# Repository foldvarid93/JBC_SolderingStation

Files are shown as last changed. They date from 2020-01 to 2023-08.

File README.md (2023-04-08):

# Welcome! 
## Actually you are watching my JBC soldering station project. 
## Version 1 will be improved at some points however it works fine too.
#### Planned Improvements:
##### Software and application 
- USB-C connector will be used to update the software in DFU mode. USB2.0 HS will be used
- FREERTOS will be used for task scheduling 
- The software application will be more flexible for migrate to other MCUs
- StemWin GUI will remain for STM32F4 or higher, 16x2 LCD driver will be used for slower MCUs 
- ...

##### Hardware and PCB
- PCB will remain the same size 
- AC transformer with triac will remain to avoid SMPS's high frequency noise
- Opamp will be revised if it is possible it will be changed to a better one
- Zero crossing detection may be changed to a more simple one
- Ambient temperature sensor and I2C connection will be removed
- ...

## ;)

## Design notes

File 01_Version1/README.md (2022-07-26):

# JBC Soldering Station 

This project was created to help people who would use a C245 and C470 JBC handle and cartridge without the expensive controller. 
There is some project on the internet what provides a solution. My first steps was also to find a complete method or solution.
Here is some already existing projects.
- [Marco Reps](https://drive.google.com/file/d/0B6S_PcWWM1YlY1lORkhDcTAzdEU/view)
- [Great Scot](https://www.instructables.com/id/DIY-Arduino-Soldering-Station)
- [Sparkybg](http://dangerousprototypes.com/forum/index.php?topic=7218.0#p61175)

## Criterias
There are some basic problems with those solution. I don't have an Arduino and I don't want to use that. 

**I wanted to...** 
- Use PID control to provide stable temperature on the end of the tip :heavy_check_mark:
- Use LCD display that I have bought long-long time ago :heavy_check_mark:
- Build the HW with components that I already had :heavy_check_mark:
- Implement sleep function :heavy_check_mark:
- Make 3D printed housing with individual design :heavy_check_mark:
- Have individual PCB design :heavy_check_mark:
- Use encoder as user input :heavy_check_mark:
- Use SPI thermocouple interface IC :heavy_multiplication_x:

So, to sum up the above mentioned points there is no universal solution. Okay, Unisolder would be the best choice, but I only want a JBC 470 compatible controller. I can't flash PICs, and the schematic is overcomplicated. (Nevertheless, I know that is an UNIversal SOLution for any types of solDERing irons...)
So I have decided that I will create my own project. The main goal was to create a good and cheap alternative, and during the prototyping I would have to learn (PID, programming, signal processing, a little power electronics, Matlab, etc).   

## 1 First steps

### 1.1 - The JBC cartridges 

Firstly I wanted to build a proper working proto HW. On the net, there are a lots of true and false informations about the cartridge. There are 2 type of people: The first typed are saying the common conductor is the red wire, and the second says green. Okay but what is the truth?



There was a person who mentioned on some electronics forum that the green is the common conductor, this is the outer sleeve of the cartridge what is supposed to be grounded (ESD safety). And there are a lots of people who says the common conductor is the pin (the end of the tip). At that point i was absolutely confused...

[I found an article on the web about these JBC cartridges.](https://patents.google.com/patent/EP1086772A2/en) According to that document the heating element is between red(common, heater1 and TC+)[2] and blue(heater2)[5] and the thermocouple is between red(heater1 and TC+)[2] and green(TC-)[1]. *[Connector pin number on the soldering iron] To make this statement absolutely true, I have performed some basic measurements on the tip. 
1. The heater is around 2-3Ohm sightly depending on the ambient temperature. For me that was ~2,5Ohm.
2. According to the sketch above, I heated up the tip with an external heat source (cigarette lighter, another soldering iron). When the tip is around 2-300°C the thermocouple generates 4-6mV. Measuring DC voltage between red and green with a multimeter, you need to see something like that values.



When you measure at 2-300°C between blue and green (heater2 and TC-) you can measure the series resistance of the TC and heater coil. When you put the positive cable on the blue and the negative on the green you need to measure higher(?) value compared with the reversed measurement (positive on the green and negative on the blue). If the difference is recognizable and we can be sure about that is not a measuring error, we can state that the first supposition is the reality.
When you are skeptic about the right consequences you can repeat the measurements with the second theorem (I did)...

### 1.2 - Ideas -> Paper sketches

### 1.3 - First prototype

I only use AVRs and STM32s, so there wasn't a question what I will use. The proto board was built around an STM32L476-Nucleo board. At this point I just wanted to be sure about the possibilities. Will it work? Can it? It need to be find out with a possible less effort. 

To contolling the LCD with a proper refresh rate STM32's computing performance was requred. The MCU is responsible for contolling the LCD, computing PID, reading TC via SPI, swithing on and off the sleep function, handling the encoder. The timing is provided by a zero crossing detector.




## 2 - Hardware

After the quick prototype I earned some experience with the system. In this section you can read my opinion with the parts.  

### 2.1 - Microcontroller

I have a lot of experience with the [STM32F446RET](https://www.st.com/en/microcontrollers-microprocessors/stm32f446.html) microcontroller. In the demo software I used this type, and I think it need to be left for the project. It can be bought under 10$. 

### 2.2 - Zero crossing detection

The demo hardware had a very simple zero crossing detector circuit. In the project it was replaced by an LM311 comparator which is not a single opa. It have a transistor on its output so driving 10mA is not problem.   




To aid my work I used TINA simulation to design a zero-crossing detector. This is a fedbacked comparator what provides rising and falling edges. The isolated DCDC converter and the optotransistor provides the galvanical isoaltion from the other parts of the schematic. A full-bridge rectifier make the sine wave to be only above the zero. The comparator sets its output according to the its imputs. If the negative input is higher the output will be 'GND' or local negative potential, and if the positive input is higher the output will be on local +VCC (~32V). The other side of the optotransistor there is an open collector output that goes to an interrupt input what is pulled up internally to the MCU +VCC potential(3,3V).

Note: This logic is reversed the original signal, but we can handle it from the sw.

The theorem is the following:

We work in 11 half waves cycles. One of them is for reading out the TC temperature data. Until the reading we need to switch off the power on the heating element because currents on the common wire can easily influence the TC's ultra sensitive signal. The first half wave of the 11 is only for the temperaure reading. After the reading(s) from the second half wave to the eleventh we can control the half waves according to the PID. We need to normalize the output "duty" to 10% steps, because we have 10 half wave and we only can switch on for integer halfwaves. So the duty is can be calculated by ONhw/11 where ONhw is the half waves when the output is ON and it goes from 0 to 10. So the effective duty is minumum 0%(obviously) and the maximum is 90%. Nevertheless, don't worry, this soldering iron can be heated up from room temperature to red glowing within 15 seconds if you are not careful with 3/11 duty. I wasn't careful enough... :(     

### 2.3 - The power stage

In the original solution there are 2 serially connected MOSFET. To save money I designed my DIY station with triac. It can be used in both half period of the sinusoidal curve.    



The switching circuit for the heating element contains an optotriac to isolate the AC power from the MCU power supply. My transformer can produce 9A current with 24V voltage and a C245 type cartridge can consumpt 130-150W during the heating up sequence. I used a typical circuit for the AC part. Fortunately there is no demand for a more complex solution. I chosed a MOC3041 optotriac with internal zero-cross detector. My plan was that I use my individual "zero-cross detector" to generate external interrupts for the MCU at every 10ms. I use the rising and falling edges to find out where the sine wave is at a certain point. Before the zero crossing, the interrupt can switch off the optotriac's LED and at the next halfwave triac will remain in off-state. In that case when thermocouple need to be read but first of all the software must wait some 100us or 1ms after the zero point to be sure the switching transients had eliminated.

### 2.4 - Thermocouple interface circuit (experimantal)

To get some experience with an interface IC, I tried the MAX31855 thermocouple IC.  



At this point there was an uncertain part of the whole project. Except the manufacturer maybe noone knows the exact type of the thermocouple in the cartridge. On the market there are available thermocouple interface IC-s from Maxim Integrated. I ordered [MAX31855](https://datasheets.maximintegrated.com/en/ds/MAX31855.pdf) IC N and K type to try out both. First of all I tried the N type. There is an additional thing about this. You can not use grounded thermocouple, so you need to find a solution because the outer sleeve of the C245 cartridge is ESD grounded via 1MOhm resistor (the tip might be ESD safe in a good soldering iron). So I needed to isolate the 5V (and 3,3V) power supply of the MCU from the ground and from the heater circuits.

The result of the experiment: This is not a proper solution to reading temperature values. The main problem is the timing. This interface IC can communicate with the MCU over SPI but the measurements cannot be performed at that point. In the background the IC refresh its registers with the actual (Okay, what is the actual? When? And where? At the top of the sinewave? Yes maybe there, maybe at the middle of the sine, so it is not deterministic...)



It can be seen, the Temperature conversion time has a massive jitter. 70 to 100ms (5 period of the line sine wave(50Hz)). In this range a specific IC can be anywhere, so we can't hold the precise timings.

### 2.6 - Thermocouple interface with a precision opamp (final solution)

What is the precison opamp? And what precison we need to perform here? In this case we have N x 10uV voltage on the thermocouple sensor. At 500°C temperature the sensor gives 10-20mV signal. We have 12bit, 3.3V ADC in the STM32. This means 4096 unit in 3.3V range. One unit is 3.3V/4096=0,0008056640625 => 0.8056640625mV =>805.6640625uV. We have 26uV Siebeck-coefficient, so the error would be 805.6640625uV/26uV/°C=31°C. This is why we need to condition the thermocouple's signal. 
There is 2 important requirements with the opamp
- The noise on the output need to be as small as possible
- The offset voltage and current need to be as small as possible (~0)
- Singe rail capability (we only have 3.3V MCU supply)
- Rail to rail output (output linearity near the positive and negative supply potential)

My choice was the [Texas Instruments OPA335](https://www.ti.com/lit/ds/symlink/opa335.pdf).  

### 2.7 - Optical isolations

Because this soldering station designed for a single 24V AC supply the power stage and the 5V MCU supply need to be separated from each other. Only one point can be common on. This is the GND. The triac is driven by an optotriac. Because the zero crossing detector uses a rectified 24V(eff) power supply what is around 32VDC, it need to be separated from the MCU pin which is 5V tolerant but normally 3.3V.
The MCU supply is galvanically separated from the rectified and puffered input supply with an isolated [Murata NCS3S4805SC](https://power.murata.com/datasheet?/data/power/ncl/kdc_ncs3.pdf) DC-DC converter .

### 2.8 - The complete schematic drawing
To sum it up, [here is the whole schematic](https://github.com/foldvarid93/JBC_SolderingStation/blob/master/Hardware/Project%20Outputs%20for%20JBC_SolderingIron/Schematic.PDF) drawing according to above mentioned points. 
You can see that I used a precision amplifier instead of a thermocouple interface IC. 
2020-01-26_10h13_12

### 2.9 - PCB design
Individual PCB was designed in Altium Designer software. The size of the board is 100x55mm. I always design with 3D components, because later I design a housing for my devices, it can be a big help if I have a precise 3D model of my PCBs. 

2019-11-19_20h41_34
2019-11-19_20h41_43
2019-11-19_20h42_02
2019-11-19_20h42_17

### 2.10 - Prototype PCB
My ptototype PCB's were made by [JLCPCB](https://jlcpcb.com) in China. I am not recommend to make PCB at home (toxic acids, vapours that can harmful for you), okay, to deliver 5 PCB with airplane not so environmentally friendly too... I left the choice for everyone. :)
I ordered my boards with 6 days shipping. The total cost is around 25$, but it can be less if you can wait 15-20 working days for the delivery.




I ordered all of components from RS Components (some components from other local stores near my home). 
[The component BOM can be found here.](https://github.com/foldvarid93/JBC_SolderingStation/blob/master/Hardware/Project%20Outputs%20for%20JBC_SolderingIron/BOM_JBC_SolderingIron.xls)
### 2.11 - Final PCB assembly 





## 4 - Software

### 4.1 - Software overview

### 4.2 - PID control loop

Just to give you a full overview to the PID, I will share my experiences with different methods.

#### 4.2.1 - Discrete PID algorithm

The first fhing that I have tired is to implement a proper discrete PID, to controlling the plant what is the temperature control for the JBC tip. At university I had some course in controlling topic, but I forgot a lot from that times. Nevertheless I had some experience with Matlab Simulink, so my first try was that. After some problem, I searched for a solution on the web.   
[I found a PID code and the controlling method here.](https://www.scilab.org/discrete-time-pid-controller-implementation)

```
void PID_Discrete(void){
	b0 = (Kp * (1 + N * Ts)) + (Ki * Ts * (1 + N * Ts))	+ (Kd * N);
	b1 = -((Kp * (2 + N * Ts)) + (Ki * Ts) + (2 * Kd * N));
	b2 = Kp + (Kd * N);
	a0 = 1 + N * Ts;
	a1 = -(2 + N * Ts);
	a2 = 1;
	A1 = a1 / a0;
	A2 = a2 / a0;
	B0 = b0 / a0;
	B1 = b1 / a0;
	B2 = b2 / a0;
	//
	E2 = E1;
	E1 = E0;
	E0 = SetPoint - T_tc;
	U2 = U1;
	U1 = U0;
	U0 = -(A1 * U1) - (A2 * U2) + (B0 * E0) + (B1 * E1)	+ (B2 * E2);
	//
	if (U0 > 100) {
		U0 = 100;
	}
	if (U0 < 0) {
		U0 = 0;
	}
	OutputDuty = (((int16_t) U0) / 10) * 10;//rounding output duty up or down to tens 0,10,...,90,100
	OutputDutyFiltered=(OutputDutyFilterCoeff1*OutputDuty+OutputDutyFilterCoeff2*OutputDutyFiltered)/100;
}
```
I have implemented the discrete method and there was massive problems with that. As I earlier said we have 11 half period from the sine curve. In the first half period (0th), tip thermocouple's temperature reading need to be performed with an ADC conversion. With 50Hz line sine frequency we have 10ms in each half period. ADC reading is performed in every 11th half period, so the sampling time is 110ms.
With this refresh period the PID control loop would be (yes it was) too lazy. Therefore I implemented a continous-like PID control algorithm. See the following chapter. 

#### 4.2.2 - "Continous" PID algorithm

At least this solution was used in my project. The basic PID equations were programmed in C language. To give some saturation to the control loop's output, the manipulated signal get some limitations (0-100). Because we only have one side manipulation over the temperature (just heating, not cooling) we need to chasing the point where we don't have overshot (not so good when you set 300°C and firstly the tip heating up to 420°C and cooling down 250°C and heating up to 340°C and so on and so on) and the heating up time is short as possible (the original can heat up from room temperature to 300 within 6seconds).  

[You can find the original solution here.](http://robotsforroboticists.com/pid-control)

```
void PID_Continous(void){
	E1 = E0;
	E0 = SetPoint - T_tc;
	Integral = Integral + (E0 * 0.11);
	if(Integral<-100){
		Integral=-100;
	}
	if(Integral>100){
		Integral=100;
	}
	Derivative = (E0 - E1) / 0.11;
	U0 = Kp*E0 + Ki*Integral + Kd*Derivative + Bias;
	if (U0 > 100) {
		U0 = 100;
	}
	if (U0 < 0) {
		U0 = 0;
	}
	OutputDuty = (((int16_t) U0) / 10) * 10;
	OutputDutyFiltered=(OutputDutyFilterCoeff1*OutputDuty+OutputDutyFilterCoeff2*OutputDutyFiltered)/100;
}
```
### 4.3 - Tuning the control loop  
For me these coefficients gave the best result. Not particularly large error in temperature (5°C overshoot) and no steady-state error. Quick heating and reaction for the disturbances thanks to the derivative term. Feel free to take some experiments in tuning your control loop to meet your demands. 

| Coefficient Name | Value  |
|---|---|
| Proportional gain - Kp | 1.7 |
| Integral gain - Ki | 0.15 |
| Derivative gain - Kd | 0.5 |

### 4.4 - User Interface

I used the free STemWin GUI library to give a simple graphic user interface for this project. As in my other projects also in this was used an inexpensive 240x320 pixel LCD module from ebay. To avoid problems I used my own low level driver for this Arduino typed LCD module.



### 4.5 - J4 Connector

##### SNC - SolderingironNotConnected: 
The system can sense the unconnected soldering iron, if you use this function. If you don't want to use, make permanent connection between GND and SNC input. If you need this feature, find the way that can connect SNC to GND when soldering iron is plugged in. My solution was that I modified the connector of the soldering iron. I soldered a free pin to the GND in the connector. When the solderint iron's connector is not connected to it's socket the SNC input will be high thanks to he pullup. When the iron's connector is plugged in to the socket, the SNC sense input will be GND (thanks to the SNC pin that shorted to the GND in the iron's connector). So this simple way can be used to determine iron is connected or not to the soldering station.        

##### SLEEP:   
It can sense if the soldering iron is in its holder. You need to make your holder from a conductor type material, I recommend aluminum, brass and copper... You need to connect the SLEEP sense input to the holder, and when you put the iron into the holder, that make contact between the ring at the lower end of the iron and the holder. The SLEEP input will be dragged down to the GND potential and the software will handle SLEEP state.  

### 4.6 - Final software

[The software can be found here.](https://github.com/foldvarid93/JBC_SolderingStation/tree/master/Software)

### 4.7 - Tests and validations
As picture show there are 11 half period, in the first period ADC measurement is performed for the thermocouple of the tip. In the left 10 periods the PID calculates the output power demands and controls the triac to hold the setpoint independently of the load on the tip.  

scope2
scope4

## 5 - Soldering iron holder  
I found that it would be easier if I buy a professional holder with tip cleaner. 



### 5.1 - Wiring of the soldering iron holder 
There are some additional function on the soldering station.   
-Can detects the connected or not connected soldering iron.
-Can detects if the soldering iron is in iron holder, and switch to lower temperature range to extend tip's lifetime. This is the sleep function. 
-Can detects if tip will be changed, and switches off the heating power.
-Can detects if soldering tip is removed.

#### Wiring schematic: 

Wiring
Modifications:  
-To get the soldering iron not connected (SNC) functionality you need to make a shortcircuit between PIN6 and PIN1 of the soldering iron's male connector.  
-To get the tip change functionality you need to modify the schematic. You need to add an other transistor and some resistors like as SNC and SLEEP. New pin need to be configured as input and handled by the software.   

#### (This is ongoing, update will come!)  

## 6 - House

## 7 - Tests, conclusions

## 8 - Additinal informations

## 9 - Some pictures of the complete soldering station





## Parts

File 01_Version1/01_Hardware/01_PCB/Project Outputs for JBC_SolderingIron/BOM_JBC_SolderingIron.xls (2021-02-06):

Designator | Quantity | Name | Value | Description | Distributor | Reference ID | Comment
B1 | 1 | HD01 – HD06 |  | 0.8A SURFACE MOUNT GLASS PASSIVATED BRIDGE RECTIFIER | RS Components | 751-4458 | HD01 – HD06
C1, C3, C4, C7, C10, C12, C15, C18, C19, C25, C26, C27, C28 | 13 |  | 100n | NON POLARIZED CAPACITOR |  |  | 100n
C2, C22 | 2 |  | 1n | NON POLARIZED CAPACITOR |  |  | 1n
C5, C6 | 2 |  | 10p | NON POLARIZED CAPACITOR |  |  | 10p
C8, C9, C14, C23, C24, C31 | 6 |  | 10n | NON POLARIZED CAPACITOR |  |  | 10n
C11, C29, C30 | 3 |  | 220uF | POLARIZED CAPACITOR |  |  | 220uF
C13, C21 | 2 |  | 4,7u | NON POLARIZED CAPACITOR |  |  | 4,7u
C16, C17 | 2 |  | 10u | POLARIZED CAPACITOR |  |  | 10u
C20 | 1 |  | 1u | NON POLARIZED CAPACITOR |  |  | 1u
D1, D2 | 2 | BAS16 | BAS16 | Low leakage current diode | RS Components | 739-0476 | BAS16
D3, D6 | 2 | BAT46WJ | BAT46WJ,115 | SCHOTTKY DIODE | RS Components | 780-5350 | BAT46WJ,115
D4, D5 | 2 | PNS40010ER | PNS40010ER,115 | Nexperia PNS40010ER,115 switching diode 1.4A, 400V, SOD-123 | RS Components | 136-4874 | PNS40010ER
EN1 | 1 | PEC11R | PEC11R-4215K-N0024 | Mechanical rotary encoder with pushbutton | RS Components | 789-9541 | PEC11R | https://hu.farnell.com/bourns/pec11r-4215k-n0024/incremental-encoder-2ch-60rpm/dp/2814034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
F1 | 1 | 696107003002 | 10A | Wurth Elektronik PCB Fuse Holder, 10 (UL) A, 6.3 (VDE) A, 250V ac | RS Components | 893-0580 | 10A
F2 | 1 |  | 500mA | FUSE | LOMEX | 44-02-32 | 500mA
J1 | 1 | T821 | T821110A1S100CEU | T821, 10pin, 2x5 connector, 2.54mm | RS Components | 832-3528 | T821110A1S100CEU
J2 | 1 | G PE | 282837-2 | 2 Pin Terminal Block | RS Components | 710-0100 | G PE
J3 | 1 | B R | 282837-2 | 2 Pin Terminal Block | RS Components | 710-0100 | B R
J4 | 1 |  | 282837-2 | 2 Pin Terminal Block | RS Components | 710-0100 | =Name
J5 | 1 | 24VAC | 282837-2 | 2 Pin Terminal Block | RS Components | 710-0100 | 24VAC
J6 | 1 |  | UART | 4 PIN HEADER |  |  | UART
JP1 | 1 | BOOT0 |  | JUMPER |  |  | BOOT0
JP2 | 1 | RESET |  | JUMPER |  |  | RESET
L1 | 1 | 3.3uH | SRN2009T-3R3M | SRN2009T-3R3M - Power Inductor (SMD), 3.3 µH, 850 mA, Semishielded, 850 mA, SRN2009T Series, 2mm x 1.6mm x 0.95mm | Farnell | 2808273 | SRN2009T-3R3M
Q1 | 1 | PMBF170 | PMBF170,215 | N-Channel MOSFET | RS Components | 484-3536 | PMBF170
Q2, Q4 | 2 | BC856 | NSVBC858CLT1G | PNP transistor, SOT23 | RS Components | 781-5109 | BC856
Q3 | 1 | T1235-600G |  | ST micro T1235-600G triac | RS Components | 811-1111 | T1235-600G
R1 | 1 |  | 220k | RESISTOR |  |  | 220k
R2, R3, R4, R5, R10, R15, R16, R18, R19, R23, R24, R25, R34, R35 | 14 |  | 10k | RESISTOR |  |  | 10k
R6, R9, R14, R31, R32 | 5 |  | 1M | RESISTOR |  |  | 1M
R7, R13, R21, R33 | 4 |  | 100k | RESISTOR |  |  | 100k
R8, R27, R28 | 3 |  | 1k | RESISTOR |  |  | 1k
R11, R17 | 2 |  | 22R | RESISTOR |  |  | 22R
R12 | 1 |  | 220R | RESISTOR |  |  | 220R
R20 | 1 |  | 470R | RESISTOR |  |  | 470R
R22 | 1 |  | 2k | RESISTOR |  |  | 2k
R26 | 1 |  | 1k5 | RESISTOR |  |  | 1k5
R29, R30 | 2 |  | ? | RESISTOR |  |  | ? | trafó kimeneti feszhez kell választani, élesztés során
U1 | 1 |  |  | 2.8 inch Adafruit LCD module
U2 | 1 | OPA335 | OPA335AID | Precision OPAMP, SO8 | RS Components | 461-8699 | OPA335AID
U3 | 1 | TLP163J |  | Toshiba TLP163J optotriac with zero crossing detector | RS Components | 885-1326 | TLP163J
U4 | 1 | STM32F446 | STM32F446RET6 | MCU STM32F446RET6 32bit, ARM Cortex M4, 180MHz, Flash, 128 kB RAM, 2xUSB USB, LQFP-64 | RS Components | 110-6621 | STM32F446 | https://hu.farnell.com/stmicroelectronics/stm32f446ret6/mcu-32bit-cortex-m4-180mhz-lqfp/dp/2488310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
U5 | 1 | LM2937 | LM2937IMP-3.3/NOPB | LDO-regulator 400mA 3,3 V 5%, 4,75 → 26 V, SOT223 | RS Components | 761-5599 | LM2937
U6 | 1 | NCS3 | NCS3S4805SC | NCS3-SINGLE DC/DC | RS Components | 876-2462 | NCS3S4805SC | https://hu.farnell.com/murata-power-solutions/ncs3s4805sc/dc-dc-converter-5v-0-6a/dp/2474813?ost=ncs3s4805sc
U7 | 1 | TMP100 | TMP100 | Temperature sensor with I2C interface |  |  | TMP100
U8 | 1 | TLP124 |  | Transistor output optocoupler TOSHIBA TLP124 | RS Components | 760-3158 | TLP124
U9 | 1 | LM311D | LM311D | LM311D - SINGLE CHANNEL W/STROBE COMPARATOR, SO8 | Farnell | 3005521 | LM311D | https://hu.farnell.com/texas-instruments/lm311d/single-channel-w-strobe-compar/dp/3005521?ost=3005521

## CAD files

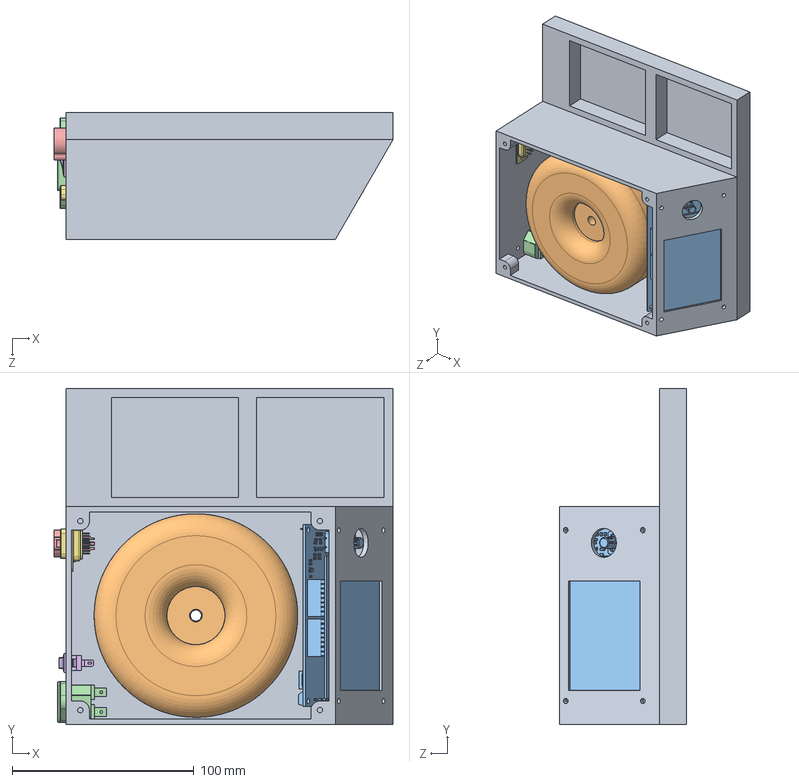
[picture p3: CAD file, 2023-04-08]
01_Version1/01_Hardware/02_3D/v2/Assem1.SLDASM
186.5 x 185.0 x 70.0 mm
haz1
Transformer
JBC_SolderingIron
PowerConn
RPC1-12RB-6P
User Library-KCD11
D-Sub_9

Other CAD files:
01_Version1/01_Hardware/02_3D/C11.sldasm
01_Version1/01_Hardware/02_3D/B1.sldasm
01_Version1/01_Hardware/02_3D/J4.sldasm
01_Version1/01_Hardware/02_3D/U5.sldasm
01_Version1/01_Hardware/02_3D/Q2.sldasm
01_Version1/01_Hardware/02_3D/SW3dPS-TO263-3S_453496017.sldasm
01_Version1/01_Hardware/02_3D/C7.sldasm
01_Version1/01_Hardware/02_3D/SW3dPS-TO263-3S_BODY5.sldasm
01_Version1/01_Hardware/02_3D/C31.sldasm
01_Version1/01_Hardware/02_3D/R7.sldasm
01_Version1/01_Hardware/02_3D/C21.sldasm
01_Version1/01_Hardware/02_3D/C26.sldasm
01_Version1/01_Hardware/02_3D/SW3dPS-TO263-3S_450155089.sldasm
01_Version1/01_Hardware/02_3D/C17.sldasm
01_Version1/01_Hardware/02_3D/LCDassembly.sldasm
01_Version1/01_Hardware/02_3D/U2.sldasm
01_Version1/01_Hardware/02_3D/J5.sldasm
01_Version1/01_Hardware/02_3D/0805_Barna_C.sldprt
01_Version1/01_Hardware/02_3D/0805_Fekete_R.sldprt
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

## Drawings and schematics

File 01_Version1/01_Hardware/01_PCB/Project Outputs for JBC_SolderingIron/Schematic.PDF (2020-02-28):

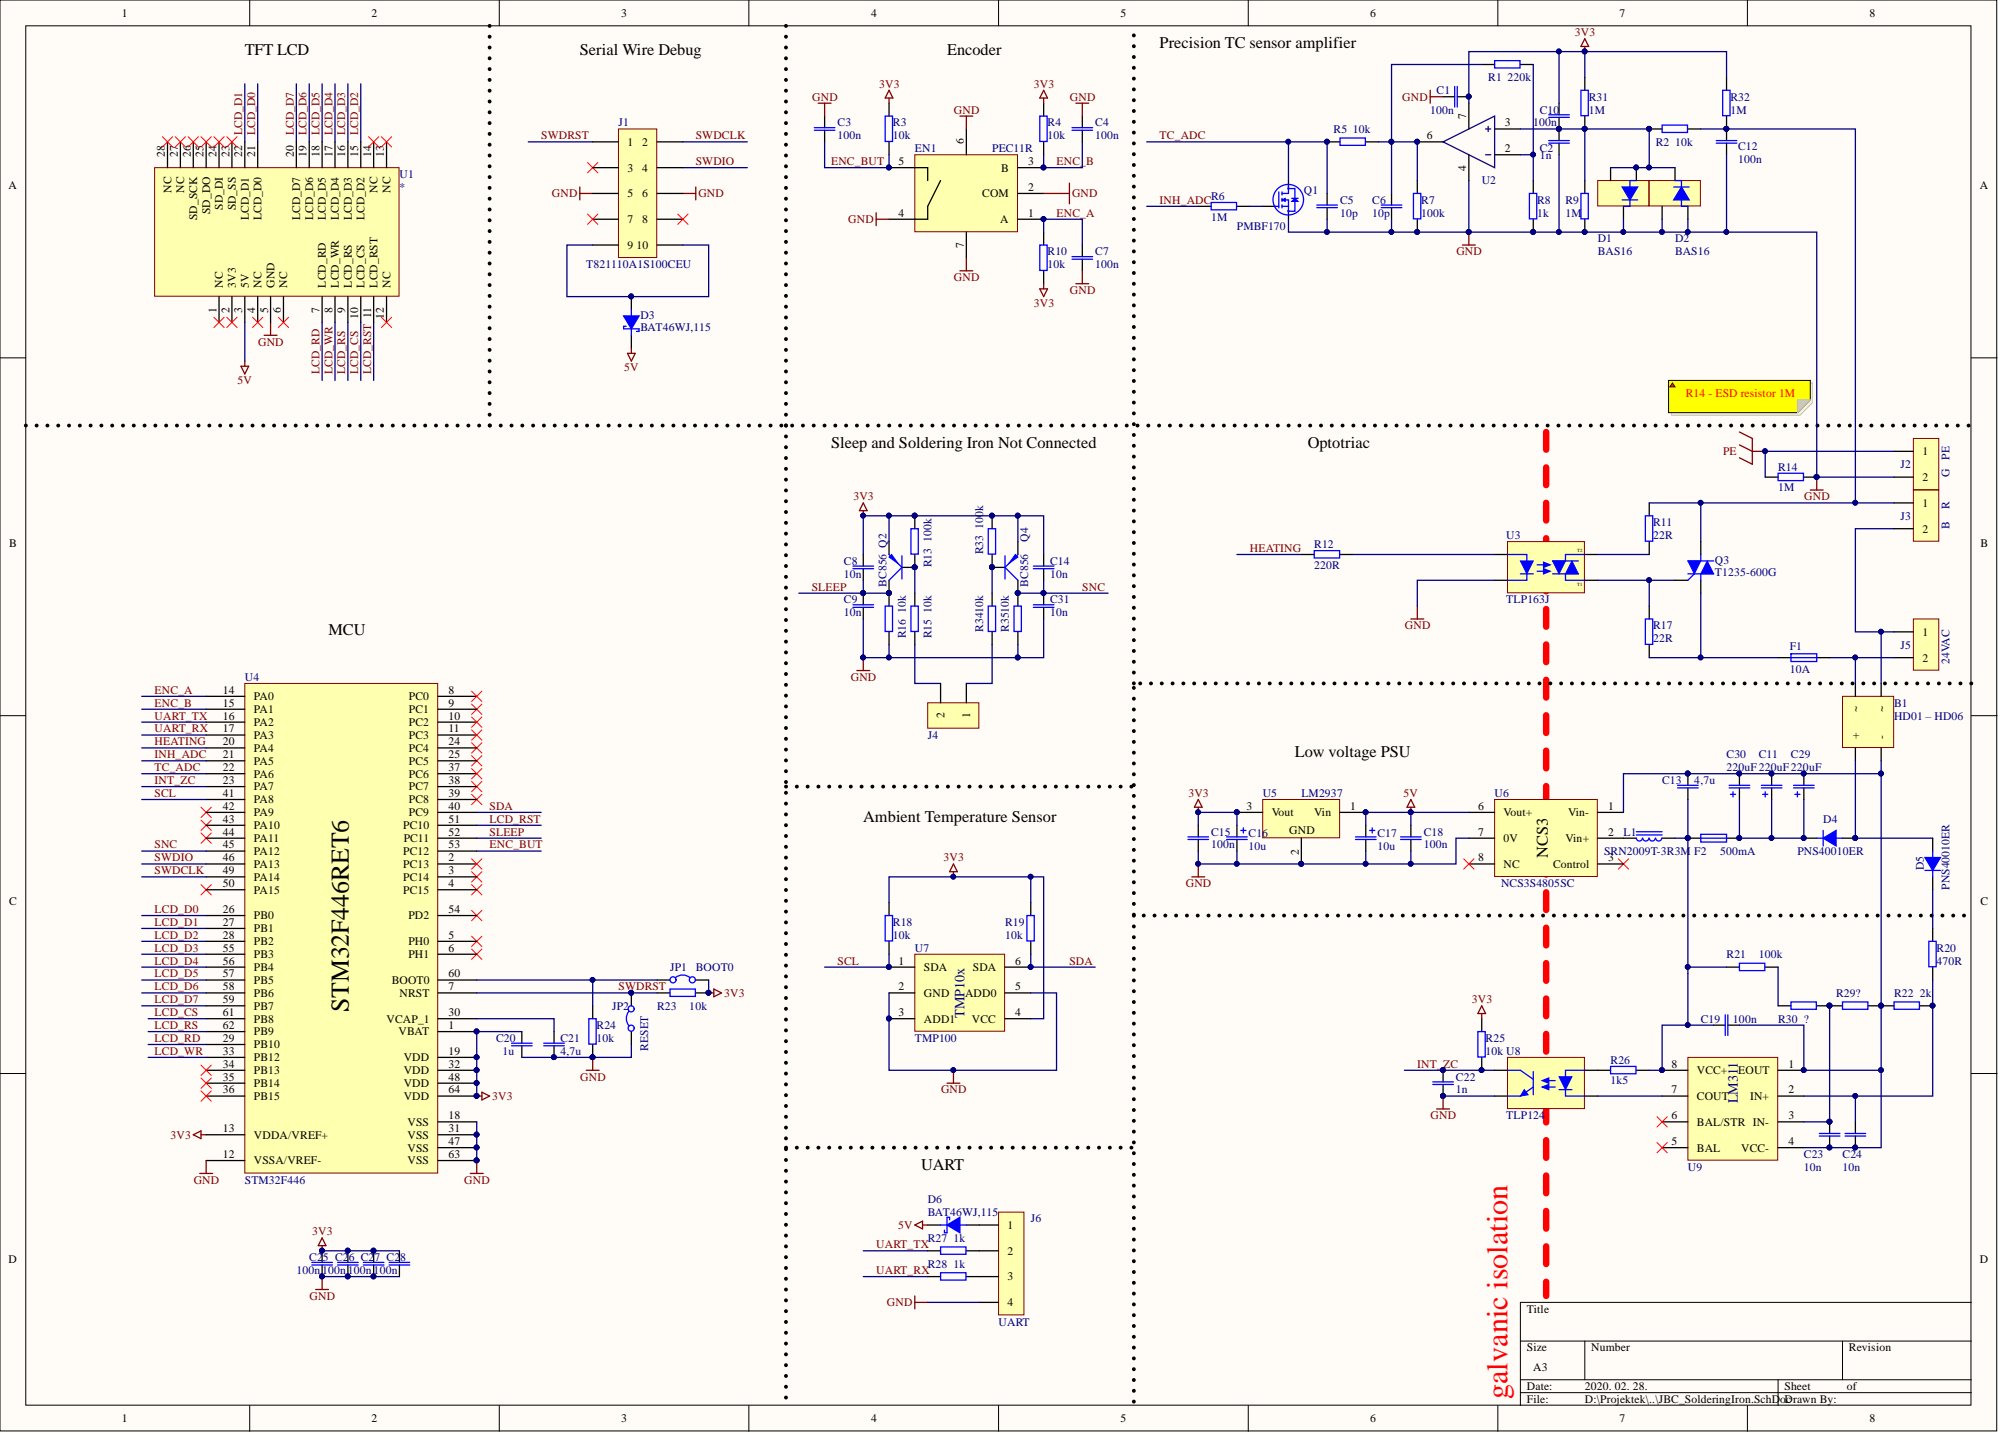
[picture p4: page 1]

Precision TC sensor amplifier

Sleep and Soldering Iron Not Connected

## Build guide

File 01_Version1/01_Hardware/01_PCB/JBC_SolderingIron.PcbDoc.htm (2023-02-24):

Reporting Options

# File in Previous Format

Date | : | 2023. 02. 24.
Time | : | 17:56:04
Filename | : | D:\Elektronika\JBC_SolderingStation\Hardware\JBC_SolderingIron.PcbDoc

Version | Warning

This file was generated by an earlier version of the software

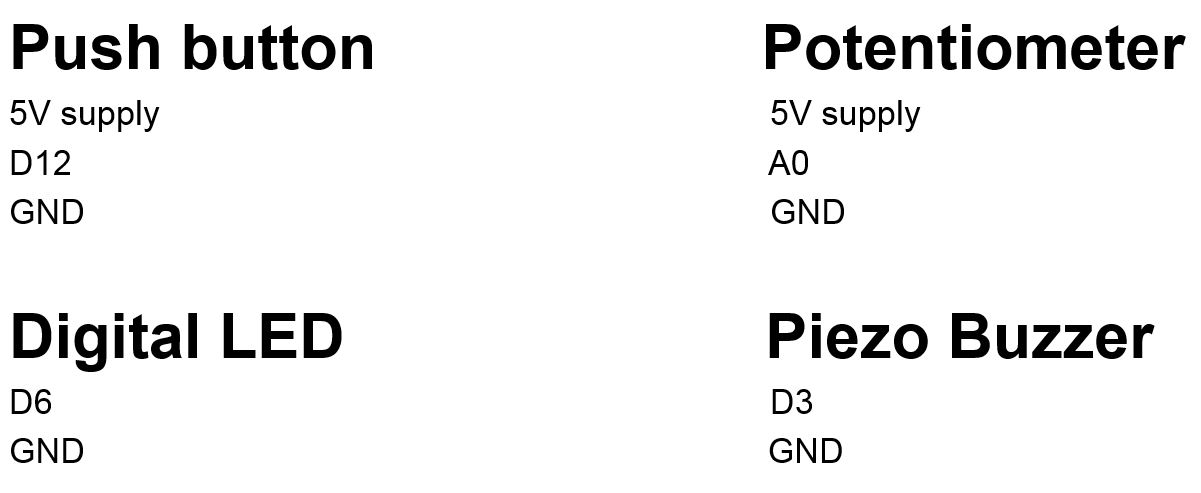
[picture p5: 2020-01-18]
01_Version1/02_Software/03_Matlab/WebinarElement14/1 ArduinoInputOutputApp/HardwareSetup.JPG

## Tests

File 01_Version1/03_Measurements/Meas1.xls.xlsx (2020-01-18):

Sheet: 1
Points | time[s] | Ostime[ms] | OutputState | TipTemp[°C] | Error[°C] | U0float[0-100] | OutputDuty[%]
0 | 0 | 11839 | 1 | 20 | 430 | 100 | 100
1 | 0.11 | 11950 | 1 | 25 | 425 | 0 | 0
2 | 0.22 | 12062 | 1 | 25 | 425 | 0 | 0
3 | 0.33 | 12173 | 1 | 25 | 425 | 16.101 | 20
4 | 0.44 | 12284 | 1 | 30 | 420 | 2.8233 | 10
5 | 0.55 | 12395 | 1 | 30 | 420 | 34.7818 | 40
6 | 0.66 | 12507 | 1 | 35 | 415 | 27.4246 | 30
7 | 0.77 | 12618 | 1 | 30 | 420 | 96.6334 | 100
8 | 0.88 | 12730 | 1 | 25 | 425 | 100 | 100
9 | 0.99 | 12841 | 1 | 30 | 420 | 60.9288 | 60
10 | 1.1 | 12952 | 1 | 40 | 410 | 12.6431 | 20
11 | 1.21 | 13064 | 1 | 45 | 405 | 16.8551 | 20
12 | 1.32 | 13175 | 1 | 50 | 400 | 19.5759 | 20
13 | 1.43 | 13286 | 1 | 55 | 395 | 21.5455 | 30
14 | 1.54 | 13398 | 1 | 60 | 390 | 23.439 | 30
15 | 1.65 | 13509 | 1 | 60 | 390 | 59.4143 | 60
16 | 1.76 | 13620 | 1 | 65 | 385 | 52.5921 | 60
17 | 1.87 | 13732 | 1 | 65 | 385 | 85.6341 | 90
18 | 1.98 | 13843 | 1 | 70 | 380 | 77.3675 | 80
19 | 2.09 | 13954 | 1 | 75 | 375 | 74.4376 | 80
20 | 2.2 | 14066 | 1 | 80 | 370 | 73.3334 | 80
21 | 2.31 | 14177 | 1 | 85 | 365 | 72.7298 | 80
22 | 2.42 | 14288 | 1 | 90 | 360 | 72.1268 | 80
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

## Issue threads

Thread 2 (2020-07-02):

JBC_SolderingStation

JHS1211, 2020-07-02:
Hello, you JBC soldering station is very good, can you put the software generated HEX firmware? Burn this firmware is very convenient, if you can, thank you very much.

JHS1211, 2020-07-05:
您好，您的JBC焊台非常好，您可以放置  软件生成的HEX固件吗？刻录此固件非常方便，如果可以的话，非常感谢。

JHS1211, 2021-01-07:
How do you not answer? If you don't want to help others, would you please tell, I won't ask you to help, is such a strange person.

JHS1211, 2021-05-21:
You can put the software generated HEX firmware? Burn this firmware is very convenient, if you can, thank you very much.

JHS1211, 2021-07-05:
Can you put the software generated HEX firmware? To burn the firmware is very convenient, if you can, thank you very much.

Closed 2022-01-04.

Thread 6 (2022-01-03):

bug of sleep Pin definition

indexdb, 2022-01-03:
change
#define SLEEP_Pin GPIO_PIN_15
#define SLEEP_GPIO_Port GPIOA

to:

#define SLEEP_Pin GPIO_PIN_11
#define SLEEP_GPIO_Port GPIOC

foldvarid93, 2022-01-04:
Why?

indexdb, 2022-01-04:
pin 15 is encoder pin not sleep pin

foldvarid93, 2022-05-26:
This issue only was on CubeIDE project. Problem fixed.

Closed 2022-05-26.

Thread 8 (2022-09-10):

request to double check the solder tip pinout definition

ntchris, 2022-09-10:
Dear sir, great project!!
For the 245 solder tip pinout, could you please double check that you can measure temperature from the 245 solder tip pin 1(green) and pin2(blue) when you have a chance ?

because I found the pinout information in your front page may not be correct ?

Anyway, to make it easier, allow me to define the largest body/shell as 1 (green in your front page),
the middle part as 2(blue),  and the smallest tail pin as 3(red).

According to my measurement, when heated with hot air gun to 40-50c, pin1(green) and 2(blue) cannot measure temperature at all (most digital multimeter can do it measure temp), while other pin combination can.
and I did it with two different clone tips from two different brand names /sellers, one is Kaisi, the other is AiXun.
base on this fact, pin 1(green) and 2(blue) should be heater pin, and not ThermalCouple pin or in serial of it at all.

On the other hand, if the front page pinout is correct, pin 1 and 2 should have been measured 40-50C (but no it couldn't ).

There is another webpage has its independent measurement has the same conclusion, by measuring resistance (tc has some tiny resistance cannot be easily measured )
http://adgd.ru/2021/01/04/jbc-soldering-cartridges-pinouts/

In that case, could you have been providing 24V to the heater through the TC ? ...

another thing, some clone handle may use random color for different pins, so....

yet another possibility, different clone tip has different pinout ??

Thanks!

foldvarid93, 2022-09-12:
Hi. Thank you for your mail and informations. You asked a big question,
because we've spent hours to figure out how it could be, and the actual
status is still not 1000% sure. So maybe you are right, you can be right,
yes. But according to my own measurements the conclusion was that you can
see in the project's github readme. After your e-mail may I will try to
wire up the iron to my soldering controller PCB as you say. But on the
other hand, there are lot of aftermarket tip on the market, so maybe they
can be different. I used original JBC cartridges. I learned measurement
technics at university, but shame on me, I dont know what could I do with
this situation. I will take a try at my company with the 4 wire ohm meter
and I will test the cartridge on some more precise measurement equipments.
If I have something new I will update the documents and write an update to
you. If you check the cross section of the tip, you can see, that gap
between TC and heater is quite nothing... But, if you flow the heater
current between C1 and C2 the current will pass through the TC element as
well, but IDK it is a real problem or not, but the situation is this. And
if you use C2 and C3 for heating and C1 and C3 for the TC the heater
current wont flow through the TC. My personal experience: It was a way more
harder to write a proper control code because the just switched off current
caused noise on the TC right before ADC measurement, and thanks to the high
gain of the OPA the ADC input saturated to VCC, this is why Great Scott's
solution is not 100% correct. https://youtu.be/UvH49nzpJts?t=567 open this
video and see how often measures 0 instead of the real temperatures. I
think the root cause of his station is that he let the current flow through
the TC element, and he don't let the sw to act based on faulty
measurements, so he just substitute faulty measurements with 0 and it was
easier for him. :D I think mine is more sophisticated, but I don't want to
be pompous. Let me know your opinion. Have a great day!
[image: image.png][image: image.png]
Best regards.

ntchris ***@***.***> ezt írta (időpont: 2022. szept. 10.,
Szo, 16:21):

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

--
[image: photo]
*Földvári*
Dávid

+36309508422 | ***@***.***
[image: Social icon] <http://www.facebook.com/foldvarid93/> [image: Social
icon] <http://www.instagram.com/foldvari.david/> [image: Social icon]
<http://www.linkedin.com/in/foldvari-david/>

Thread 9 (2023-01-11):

T245 Handle

Grininventor, 2023-01-11:
Hi, I really like your project and I want to make my own soldering station, but I wold like to use a JBC T245 handle, do I have to do some modification to your design in order to make it work with this handle ?

Grininventor, 2023-01-11:
Also, how can I make the PCB ?
I can't find how to convert the files you share to gerber.
Can you help me please ?

foldvarid93, 2023-02-24:
Hi. The project is designed in Altium Designer. It is not a free tool, but you can find a way how to use it. If you are not familiar with the tool, you can design your own PCB or just use the generated fabrication output in the last commit.
https://github.com/foldvarid93/JBC_SolderingStation/commit/78a58907aa42c05f058115dce05929afd02a5fa9

foldvarid93, 2023-02-24:
> Hi, I really like your project and I want to make my own soldering station, but I wold like to use a JBC T245 handle, do I have to do some modification to your design in order to make it work with this handle ?

As fas as I know the T245 is same as T470 handle, so you can use it without any problems.

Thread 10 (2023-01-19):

R29, R30 And getting rid of isolated dc dc converter.

aycarambaa, 2023-01-19:
Hi, I like your soldering station design. Unfortunately, I am unable to find any information on R29 and R30, what formula should I use to calculate it?

My next idea is to simplify the scheme a bit by getting rid of the isolated converter and simply adding a wrapped transformer winding. Do you think it will work fine?

foldvarid93, 2023-02-24:
Hi. The idea behind the DC-DC converter was simple. I had to use a single secunder wired transformer for the whole design. If you can solve this problem with a double winded transformer instead of the DC-DC converter, you can do it. The supply of the MCU need to be separated from the power part. I used optocouplers and isolated supplies, but you can reimagine it if you have better idea. Please if you can rationalize the project share your idea with us. :) And the R29 and R30 need to be selected for your HW individually. You need to tune the treshold values for the zero crossing detector as presice as possible. I used a variable resistor and measured the output od the comparator. When I found the settings which is narrow enough and robust enough at the same time I changed the variabe resistor to fix one(s) this is why I designed the feedback voltage divider like i did. If you get an exotic value you can use 2 different resistor to get the perfect value for the divider. If it is not needed you can make a solder bridge from one of the series resistors' pads. :)

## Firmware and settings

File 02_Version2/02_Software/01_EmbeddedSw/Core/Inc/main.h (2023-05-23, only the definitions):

#define ENC_A_Pin GPIO_PIN_0
#define ENC_A_GPIO_Port GPIOA
#define ENC_B_Pin GPIO_PIN_1
#define ENC_B_GPIO_Port GPIOA
#define HEATING_Pin GPIO_PIN_4
#define HEATING_GPIO_Port GPIOA
#define INH_ADC_Pin GPIO_PIN_5
#define INH_ADC_GPIO_Port GPIOA
#define INT_ZC_Pin GPIO_PIN_7
#define INT_ZC_GPIO_Port GPIOA
#define INT_ZC_EXTI_IRQn EXTI9_5_IRQn
#define LCD_D0_Pin GPIO_PIN_0
#define LCD_D0_GPIO_Port GPIOB
#define LCD_D1_Pin GPIO_PIN_1
#define LCD_D1_GPIO_Port GPIOB
#define LCD_D2_Pin GPIO_PIN_2
#define LCD_D2_GPIO_Port GPIOB
#define LCD_RD_Pin GPIO_PIN_10
#define LCD_RD_GPIO_Port GPIOB
#define LCD_WR_Pin GPIO_PIN_12
#define LCD_WR_GPIO_Port GPIOB
#define SDA_Pin GPIO_PIN_9
#define SDA_GPIO_Port GPIOC
#define SCL_Pin GPIO_PIN_8
#define SCL_GPIO_Port GPIOA
#define SNC_Pin GPIO_PIN_12
#define SNC_GPIO_Port GPIOA
#define SNC_EXTI_IRQn EXTI15_10_IRQn
#define SWDIO_Pin GPIO_PIN_13
#define SWDIO_GPIO_Port GPIOA
#define SWDCLK_Pin GPIO_PIN_14
#define SWDCLK_GPIO_Port GPIOA
#define SLEEP_Pin GPIO_PIN_15
#define SLEEP_GPIO_Port GPIOA
#define SLEEP_EXTI_IRQn EXTI15_10_IRQn
#define LCD_RST_Pin GPIO_PIN_10
#define LCD_RST_GPIO_Port GPIOC
#define ENC_BUT_Pin GPIO_PIN_11
#define ENC_BUT_GPIO_Port GPIOC
#define ENC_BUT_EXTI_IRQn EXTI15_10_IRQn
#define LCD_D3_Pin GPIO_PIN_3
#define LCD_D3_GPIO_Port GPIOB
#define LCD_D4_Pin GPIO_PIN_4
#define LCD_D4_GPIO_Port GPIOB
#define LCD_D5_Pin GPIO_PIN_5
#define LCD_D5_GPIO_Port GPIOB
#define LCD_D6_Pin GPIO_PIN_6
#define LCD_D6_GPIO_Port GPIOB
#define LCD_D7_Pin GPIO_PIN_7
#define LCD_D7_GPIO_Port GPIOB
#define LCD_CS_Pin GPIO_PIN_8
#define LCD_CS_GPIO_Port GPIOB
#define LCD_RS_Pin GPIO_PIN_9
#define LCD_RS_GPIO_Port GPIOB
#define LCD_DATA_PORT GPIOB

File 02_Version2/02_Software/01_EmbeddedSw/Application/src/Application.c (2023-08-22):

/*
 * Application.c
 *
 *  Created on: Nov 1, 2019
 */

#include "Application.h"
extern volatile GUI_TIMER_TIME OS_TimeMS;
/*Uart variables*/
char UartRxData[100];
char UartTxData[100];
/**/
uint8_t Index = 0;
uint16_t SetPoint;
uint16_t SetPointBackup;
bool EncoderChanged=false;
uint8_t ChangedEncoderValueOnScreen=0;
/*Temperature measurement variables*/
float ADCData = 0;
float TEST_ADCData;
float T_tc = 0;
float T_amb = 20;
float U_measured;
const float U_seebeck = 26.2;
const float VoltageMultiplier = 3.662; /*33000000/(4096*220)=3.662*/
uint16_t MovingAverage_T_tc = 0;
uint16_t Points = 0;
bool OutputState = false;
uint8_t FirstRunCounter = 0;
/*PID variables*/
uint8_t OutputDuty = 10;
uint8_t OutputDutyFiltered = 0;
float Ts = 0.11;
uint8_t N = 5;
float Kp = 1.7;
float Ki = 0.15;
float Kd = 0.5;
float E0 = 0;
float E1 = 0;
float E2 = 0;
float U0 = 0;
float U1 = 0;
float U2 = 0;
float a0;
float a1;
float a2;
float b0;
float b1;
float b2;
float A1;
float A2;
float B0;
float B1;
float B2;
/**/
float Derivative=0;
float Integral=0;
float Bias=0;
/**/
/*state machine variables*/
bool SolderingIronIsInHolder;	/*1 if soldering iron is in the Holder*/
bool SolderingTipIsRemoved=false;/*new PCB version can distinguish removed tip and unconnected soldering iron*/
bool SolderingIronNotConnected;/*1 if soldering iron unconnected*/
extern WM_HWIN hDialog;		/**/
extern WM_HWIN hText_0;		/*Set Temperature*/
extern WM_HWIN hText_1;		/*setpoint*/
extern WM_HWIN hText_2;		/*°C*/
extern WM_HWIN hText_3;		/*Soldering Iron Temperature*/
extern WM_HWIN hText_4;		/*actual temp*/
extern WM_HWIN hText_5;		/*°C*/
extern WM_HWIN hText_6;		/*Heating power*/
extern WM_HWIN hProgbar_0;	/*progress bar*/
/*Flash variables*/
bool FlashWriteEnabled=true;
uint16_t VirtAddVarTab;
/**/
uint16_t Counter = 0;
uint8_t Cnt2=0;
bool CounterFlag = false;
/*defines*/
#define BlinkingPeriod 						750									/*ms period time of blinking texts*/
#define ChangedEncoderValueOnScreenPeriod 	4									/*4*BlinkingPeriod*/
#define TemperatureMovingAverageCoeff1 		0.6									/*must be between 0 and 1*/
#define TemperatureMovingAverageCoeff2 		(1-TemperatureMovingAverageCoeff1)
#define OutputDutyFilterCoeff1 				0.5									/*must be between 0 and 1*/
#define OutputDutyFilterCoeff2 				(1-OutputDutyFilterCoeff1)
#define EncoderOffset 						0x7FFF
/**/
/*#define SendMeasurementsTimer*/
#ifdef SendMeasurementsTimer
#define SendMeasurementsPeriod 				110									/*ms*/
#endif

/*Converts a floating point number to string.*/
/*float to char array conversion*/
void ftoa(float n, char *res, int afterpoint)
{
	/*Extract integer part*/
	int ipart = (int) n;
	/*Extract floating part*/
	float fpart = n - (float) ipart;

	if (fpart < 0 || ipart < 0) {
		res[0] = '-';
		if (ipart < 0) {
			ipart *= -1;
		}
		if (fpart < 0) {
			fpart *= -1;
		}
		itoa(ipart, res + 1, 10);
	}
	/*convert integer part to string*/
	else {
		itoa(ipart, res, 10);
	}
	int i = strlen(res);
	if (afterpoint != 0) {
		res[i] = '.';
		fpart = fpart * pow(10, afterpoint);
		itoa((int) fpart, res + i + 1, 10);
	}
}
/*send measurements*/
void SendMeasurements(void)
{
	char TmpBuffer[20];
	/*Measuring Points*/
	itoa(Points, TmpBuffer, 10);
	strcpy(UartTxData, TmpBuffer);
	strcat(UartTxData, "; ");
	/*ms value*/
	itoa(OS_TimeMS, TmpBuffer, 10);
	strcat(UartTxData, TmpBuffer);
	strcat(UartTxData, "; ");
	/*Output 0 or 1*/
	itoa(OutputState, TmpBuffer, 10);
	strcat(UartTxData, TmpBuffer);
	strcat(UartTxData, "; ");
	/*SetPoint temperature*/
	itoa(SetPoint, TmpBuffer, 10);
	strcat(UartTxData, TmpBuffer);
	strcat(UartTxData, "; ");
	/*Tip temperature*/
	itoa(MovingAverage_T_tc, TmpBuffer, 10);
	strcat(UartTxData, TmpBuffer);
	strcat(UartTxData, "; ");
	/*actual error signal*/
	ftoa(E0, TmpBuffer, 4);
	strcat(UartTxData, TmpBuffer);
	strcat(UartTxData, "; ");
	/*Actual manupilator signal*/
	ftoa(U0, TmpBuffer, 4);
	strcat(UartTxData, TmpBuffer);
	strcat(UartTxData, "; ");
	/*ftoa(U0,TmpBuffer,4)*/
	/*output duty*/
	itoa(OutputDuty, TmpBuffer, 10);
	strcat(UartTxData, TmpBuffer);
	strcat(UartTxData, "\r\n");
	/*send*/
	HAL_UART_Transmit(&huart2, (uint8_t*) UartTxData, strlen(UartTxData), 100);
	Points++;
}
/*PID Continous*/
void PID_Continous(void)
{
	E1 = E0;
	E0 = SetPoint - T_tc;
	Integral = Integral + (E0 * 0.11);
	if(Integral<-100){
		Integral=-100;
	}
	if(Integral>100){
		Integral=100;
	}
	Derivative = (E0 - E1) / 0.11;
	U0 = Kp*E0 + Ki*Integral + Kd*Derivative + Bias;
	if (U0 > 100) {
		U0 = 100;
	}
	if (U0 < 0) {
		U0 = 0;
	}
	OutputDuty = (((int8_t) U0) / 10) * 10;
	OutputDutyFiltered  = (((uint8_t)(OutputDutyFilterCoeff1*OutputDuty+OutputDutyFilterCoeff2*OutputDutyFiltered))/10)*10;
}
/*interrupt task handler*/
void InterruptTaskHandler(uint16_t GPIO_Pin)
{
/*----------------------------------------------------------------------------------------------*/
/*Zero Crossing Detector External Interrupt*/
	if (GPIO_Pin == INT_ZC_Pin)
	{
		/*if GPIO==1 rising edge before zero crossing*/
		if (HAL_GPIO_ReadPin(INT_ZC_GPIO_Port, INT_ZC_Pin) == 1)
			{
			if (Index == 0) /*under the first half-wave ADC measurement is performed*/
				{
#ifdef DEBUG
				ADCData = TEST_ADCData;

#else			/*ACD+precision OPA*/

				HAL_GPIO_WritePin(INH_ADC_GPIO_Port, INH_ADC_Pin,GPIO_PIN_RESET); /*Release the ADC input*/

				vTaskDelay(5);

				/*Start AD conversion*/
				HAL_ADC_Start(&hadc1);

				if (HAL_ADC_PollForConversion(&hadc1, 100) == HAL_OK) /*ADC read*/
				{
					ADCData = HAL_ADC_GetValue(&hadc1); /*Add new adc value to the variable*/
				}
				HAL_GPIO_WritePin(INH_ADC_GPIO_Port, INH_ADC_Pin,GPIO_PIN_SET); /*Pull down the the ADC input*/
				HAL_ADC_Stop(&hadc1); /*stop the ADC module*/
#endif
				if (ADCData > 3500)
				{
					SolderingTipIsRemoved = true;
					OutputState = false;
					OutputDuty = 0;
				}
				else
				{
					SolderingTipIsRemoved = false;
					OutputState = true;
					/*convert to celsius*/
					U_measured = ADCData * VoltageMultiplier; /*measured TC voltage in microvolts = Uadc(LSB) *3.662*/
					T_tc = (U_measured / U_seebeck) + T_amb; /*Termocoulpe temperature=Measured voltage/seebeck voltage+Ambient temperature (cold junction compensation)*/
					MovingAverage_T_tc = (uint16_t)(T_tc * TemperatureMovingAverageCoeff1 + MovingAverage_T_tc * TemperatureMovingAverageCoeff2);/*exponential filter with 2 sample and lambda=0.8*/
					MovingAverage_T_tc = ((MovingAverage_T_tc + 4) / 5) * 5;/*rounding to 0 or 5 MovingAverage_T_tc=T_tc;*/
					if (MovingAverage_T_tc > SetPoint * 1.1)
					{
						OutputState = false;
					}
				}
				if(FirstRunCounter < NumberOfADCSampleAvegrage)
				{
					OutputState = false;
					FirstRunCounter++;
				}
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

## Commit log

2020-01-18 remove dead code segments Signed-off-by: foldvarid93 <foldvarid93@gmail.com>
    [JBC_SolderingIron.PrjPcb, JBC_SolderingIron.SchDoc, Meas1.xls.xlsx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]
2020-01-19 New PID algorithm
2020-01-25 3D: case design SW: EEPROM RW bugfix
    [Application.c]
2020-01-26 Creating CUBEIDE project from Attolic Truestudio project
    [446RE_JBC_SolderingIron Debug.cfg]
2020-01-31 3D drawings added
    [JBC_SolderingIron.PrjPcb]
2020-02-28 BOM generated
    [BOM_JBC_SolderingIron.xls]
2021-02-06 Power-up temperature overshoot eliminated
    [BOM_JBC_SolderingIron.xls, JBC_SolderingIron.PrjPcb]
2021-02-06 readme updated J4 connector
2021-02-20 add PID coefficients
2022-05-26 Readme.md modification: wiring up aliexpress soldering iron holder.
2022-05-26 clean up dead codes
    [446RE_JBC_SolderingIron Debug.cfg]
2022-07-26 Attolic Truestudio upgrade 9.2->9.3 debug error fixed
    [Application.c, eeprom.c]
2023-02-24 HW design update -Fabrication output generated in PCB_Fabrication.zip -Output job update
    [JBC_SolderingIron.PrjPcb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]
2023-04-08 Version2 folder structure created
    [0805_Barna_C.sldprt, 0805_Fekete_R.sldprt, 12mm_Incremental_Encoder_Anti-Rotation_Plate_1.sldprt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]
2023-04-08 PCB project added
    [JBC_SolderingIron.PrjPcb, JBC_SolderingIron.SchDoc]
2023-05-23 freeRTOS Interrupt implementation
2023-06-05 external interrupt problem fix
    [Application.c, JBC_SolderingIron_446RE.ioc]

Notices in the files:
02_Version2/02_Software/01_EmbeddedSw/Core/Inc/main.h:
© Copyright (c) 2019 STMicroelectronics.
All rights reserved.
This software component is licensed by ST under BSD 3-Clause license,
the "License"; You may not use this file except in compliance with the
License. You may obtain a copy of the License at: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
